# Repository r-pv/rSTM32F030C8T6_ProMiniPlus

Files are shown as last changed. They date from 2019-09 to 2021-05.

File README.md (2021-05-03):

# rSTM32F030C8T6 ProMini+
An ST development board based on the STM32F030C8T6 (Clock: 48MHz, Flash: 64Kb, Ram:8Kb) MCU compatible with STM32Duino (Arduino). 

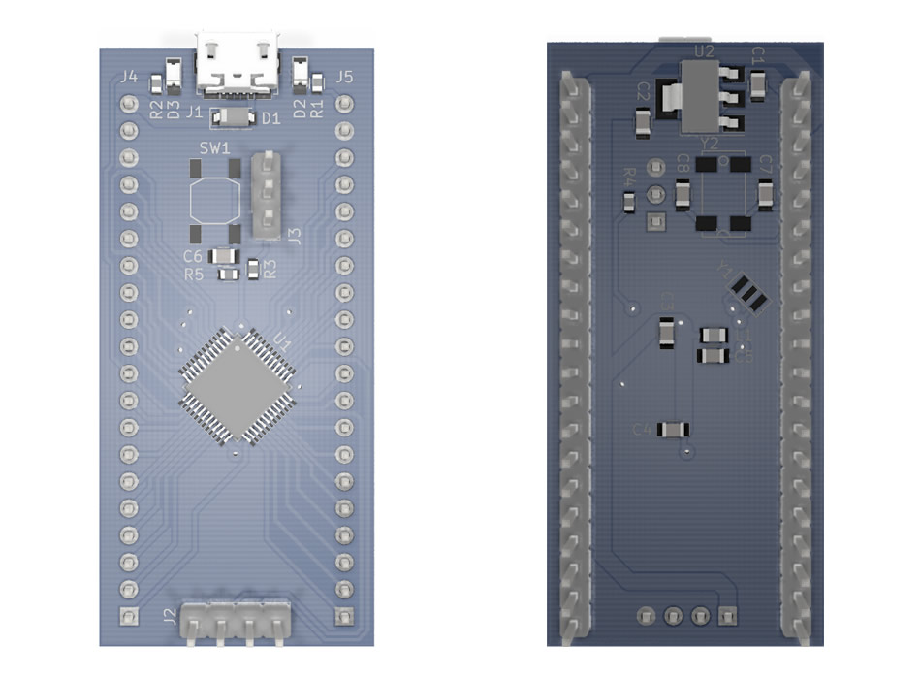
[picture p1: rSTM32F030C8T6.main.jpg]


Pinout:

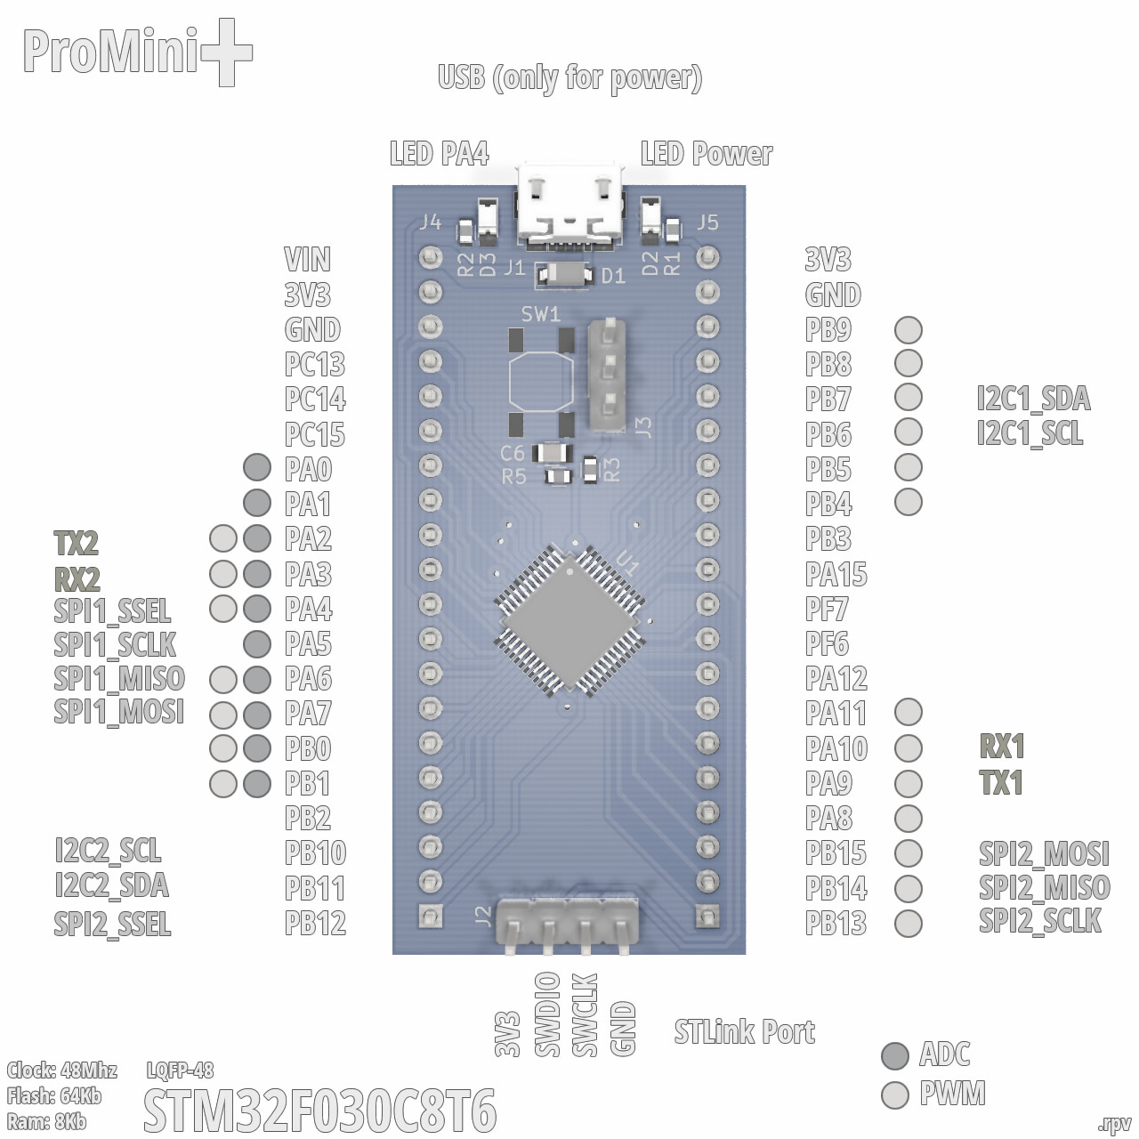
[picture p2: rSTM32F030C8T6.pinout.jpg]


## Files and Folders description

- **RBOARD_F030C8T6** it's the variant board for the STM32 Arduino Core.
- **rSTM32F030C8T6** it's the KiCAD 5.1.2 project.
- **rSTM32F030C8T6.schematic.pdf** the schematic.

## Install

**Update:** STCore v2.0 includes support for this MCU, if you're using STCore v2.0 you don't need to install anything.

- This requires the [STM32 core for arduino](https://github.com/stm32duino/Arduino_Core_STM32/), the ST original.
- I used this [guide to add the board](https://github.com/stm32duino/wiki/wiki/Add-a-new-variant-(board)), you can check it or continue with my suggestions to install the new board.
- Copy the **"RBOARD_F030C8T6"** folder to the Arduino **"variants"** folder, in win7 is located at: **c:\Users\\<USERNAME\>\AppData\Local\Arduino15\packages\STM32\hardware\stm32\1.6.1\variants**
- Edit the **"boards.txt"** file, in win7 is located at a lever up than the "variants" folder, search for the **F030F4** board and add the lines to leave it as I show you next:

```
# DEMO_F030F4 board
# Support: Serial1 (USART1 on PA3, PA2)
GenF0.menu.pnum.DEMO_F030F4=STM32F030F4 Demo board
GenF0.menu.pnum.DEMO_F030F4.upload.maximum_data_size=4096
GenF0.menu.pnum.DEMO_F030F4.upload.maximum_size=16384
GenF0.menu.pnum.DEMO_F030F4.build.mcu=cortex-m0
GenF0.menu.pnum.DEMO_F030F4.build.board=DEMO_F030F4
GenF0.menu.pnum.DEMO_F030F4.build.series=STM32F0xx
GenF0.menu.pnum.DEMO_F030F4.build.product_line=STM32F030x6
GenF0.menu.pnum.DEMO_F030F4.build.variant=DEMO_F030F4
GenF0.menu.pnum.DEMO_F030F4.build.cmsis_lib_gcc=arm_cortexM0l_math

# RBOARD_F030C8T6 board
# Support: Serial1 (USART1 on PA3, PA2)
GenF0.menu.pnum.RBOARD_F030C8T6=STM32F030C8 STProMiniPlus
GenF0.menu.pnum.RBOARD_F030C8T6.upload.maximum_data_size=8192
GenF0.menu.pnum.RBOARD_F030C8T6.upload.maximum_size=65536
GenF0.menu.pnum.RBOARD_F030C8T6.build.mcu=cortex-m0
GenF0.menu.pnum.RBOARD_F030C8T6.build.board=RBOARD_F030C8T6
GenF0.menu.pnum.RBOARD_F030C8T6.build.series=STM32F0xx
GenF0.menu.pnum.RBOARD_F030C8T6.build.product_line=STM32F030x8
GenF0.menu.pnum.RBOARD_F030C8T6.build.variant=RBOARD_F030C8T6
GenF0.menu.pnum.RBOARD_F030C8T6.build.cmsis_lib_gcc=arm_cortexM0l_math
```

## The real board

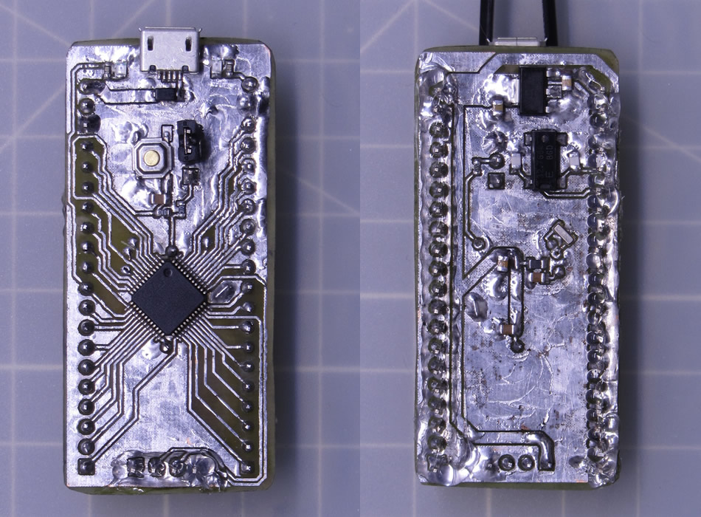
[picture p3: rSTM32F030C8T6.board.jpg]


## Running some tests

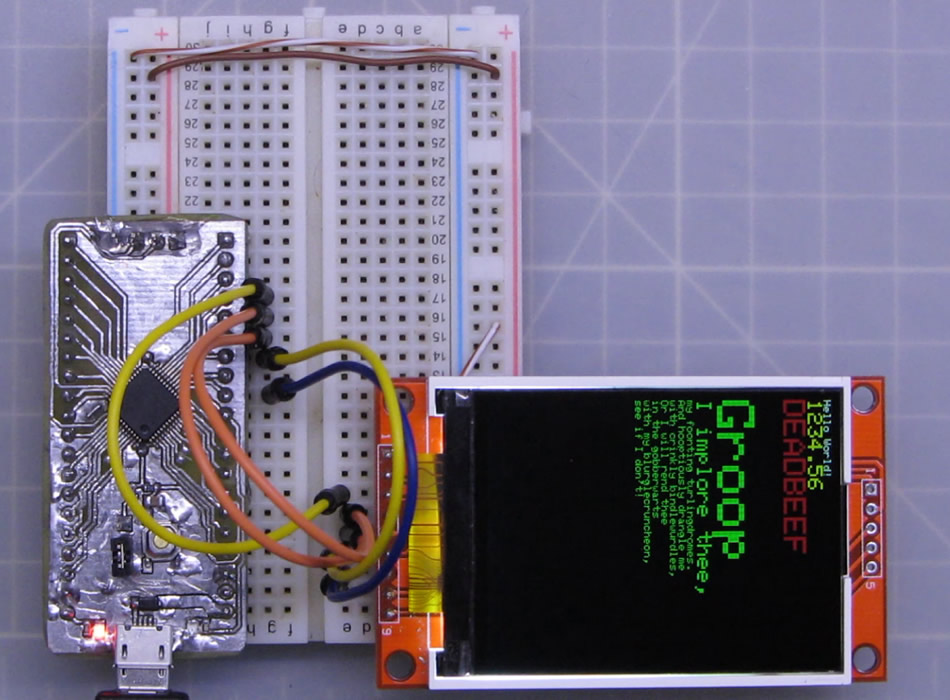
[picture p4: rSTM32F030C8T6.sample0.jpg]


The **ProMini+** running the Adafruit ILI9341 library over hardware SPI.

_Video in progress..._

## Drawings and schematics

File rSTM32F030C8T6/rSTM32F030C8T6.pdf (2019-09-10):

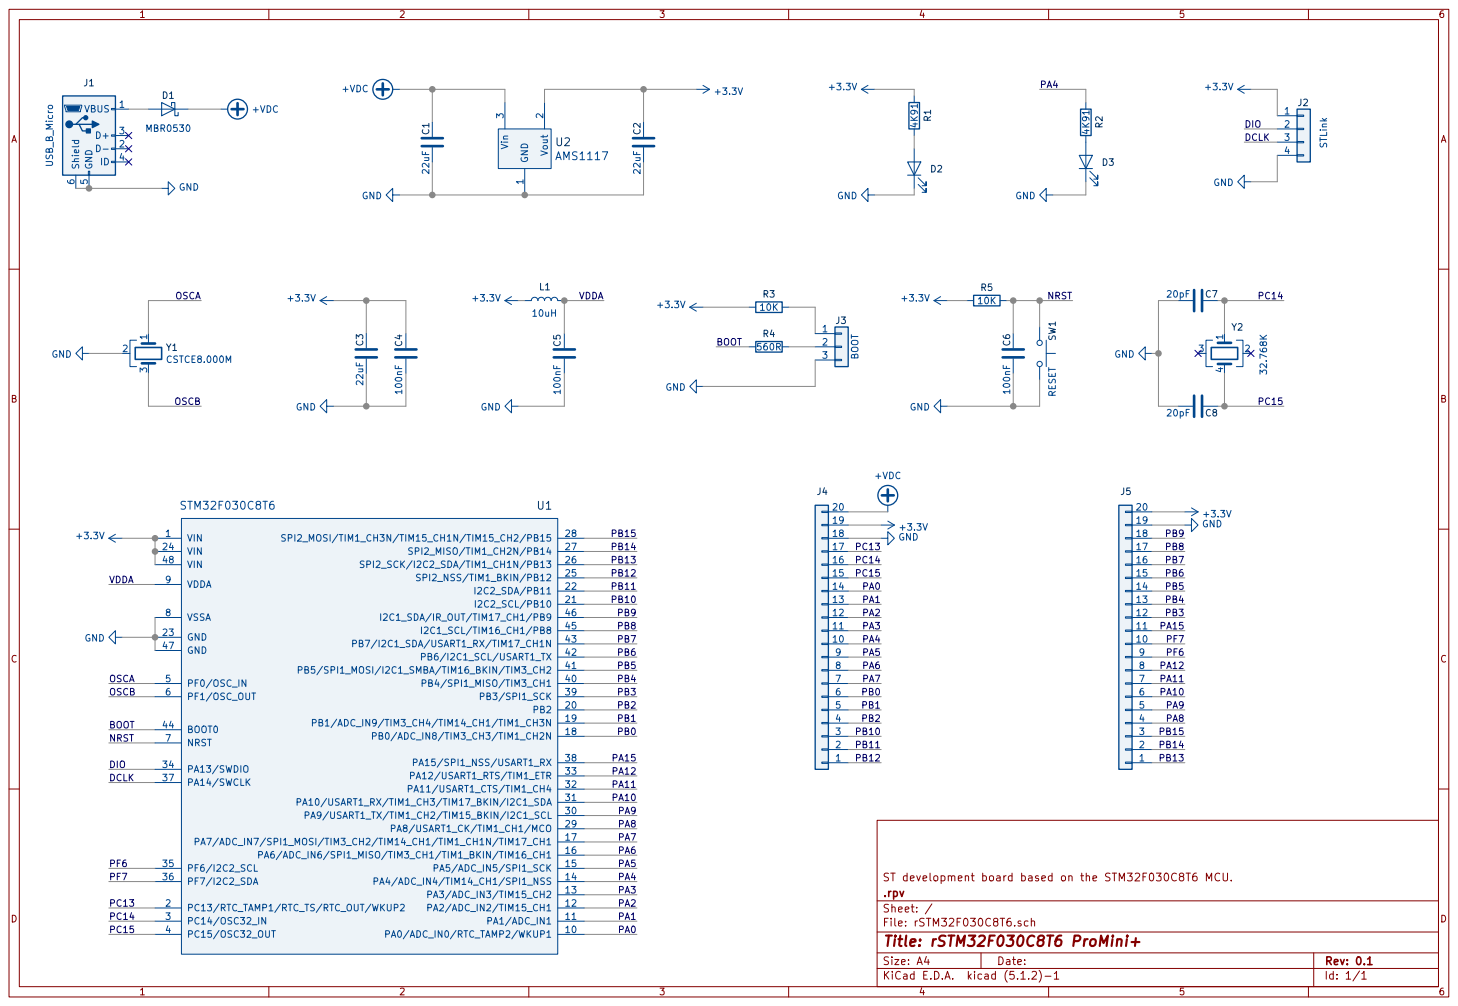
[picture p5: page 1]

.rpv ST development board based on the STM32F030C8T6 MCU. GND

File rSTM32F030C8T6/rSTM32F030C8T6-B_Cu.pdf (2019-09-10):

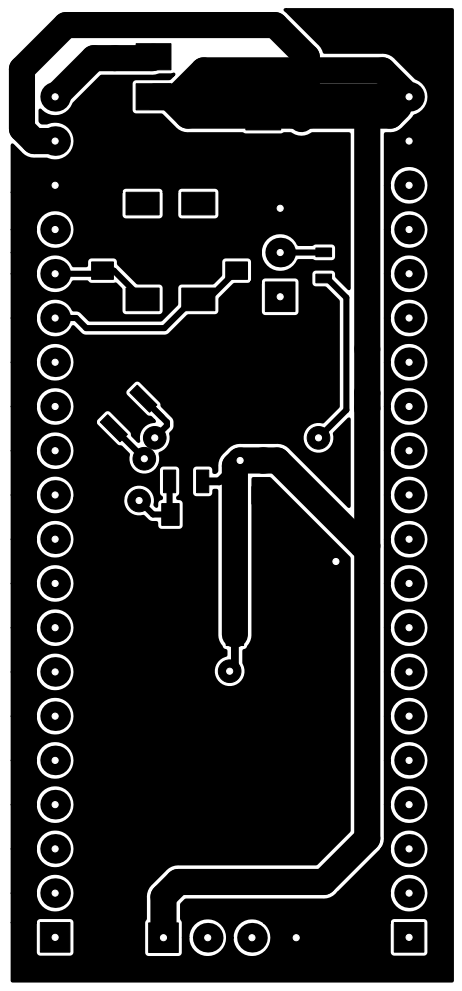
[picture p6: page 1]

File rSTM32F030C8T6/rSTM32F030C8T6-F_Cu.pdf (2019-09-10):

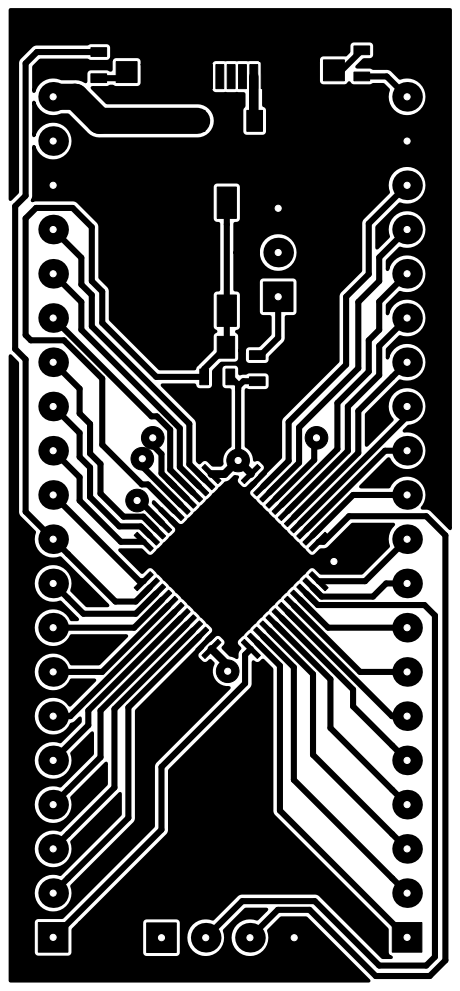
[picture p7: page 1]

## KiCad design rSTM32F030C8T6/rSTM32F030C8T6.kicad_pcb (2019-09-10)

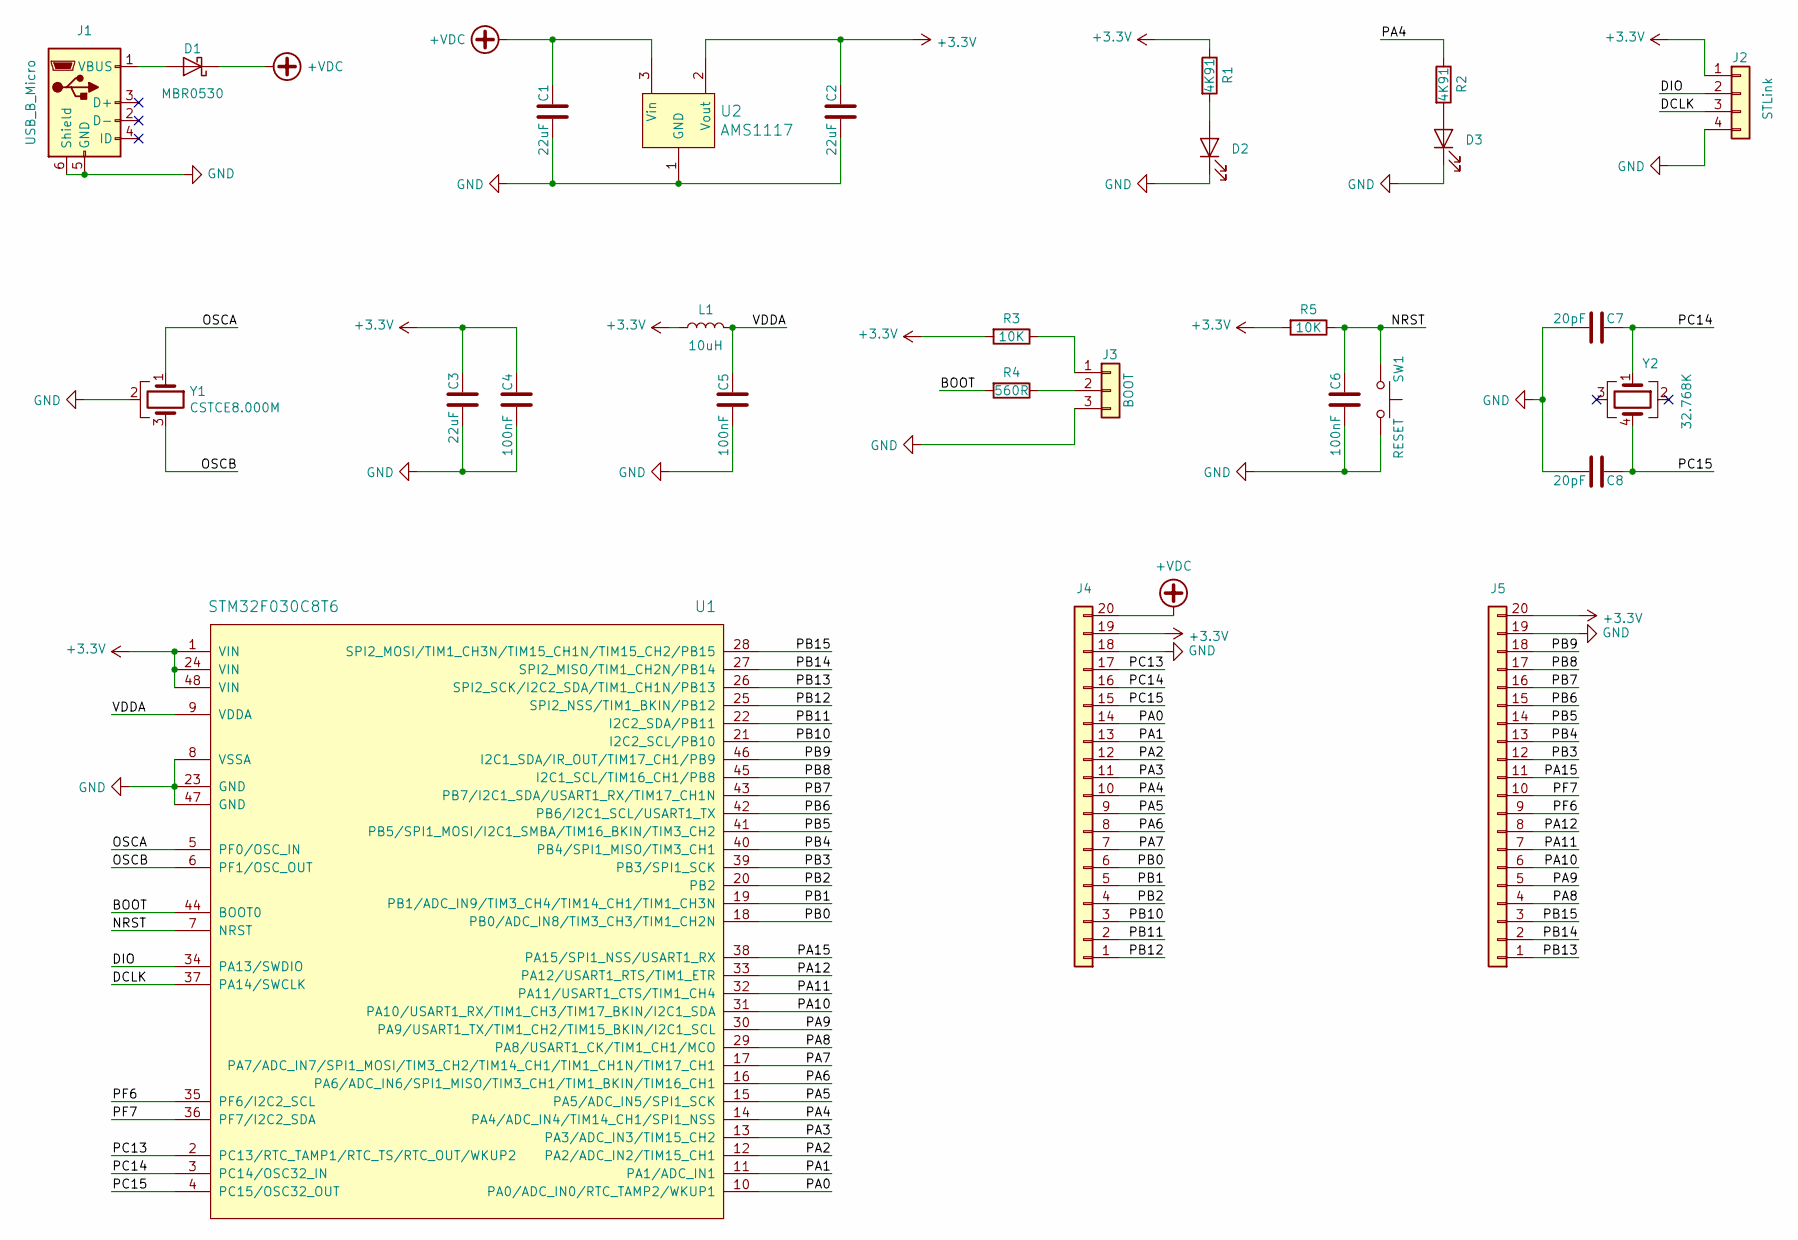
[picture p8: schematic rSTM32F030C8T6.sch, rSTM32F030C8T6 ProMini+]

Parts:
C1, C2, C3: 22uF; C_0805
C4, C5, C6: 100nF; C_0805
C7, C8: 20pF; C_0805
D1: MBR0530; D_SOD-123
D2, D3: LED; LED_0805
J1: USB_B_Micro; USB_Micro-B_Molex_47346-0001
J2: STLink; Pin_Header_Straight_1x04_Pitch2.54mm
J3: BOOT; Pin_Header_Straight_1x03_Pitch2.54mm
J4, J5: Pin_Header_Straight_1x20_Pitch2.54mm
L1: 10uH; L_0805
R1, R2: 4K91; R_0603
R3, R5: 10K; R_0603
R4: 560R; R_0603
SW1: RESET; Switch_SMD_5.2x6.4_reset
U1: STM32F030C8T6; LQFP-48_7x7mm_Pitch0.5mm
U2: AMS1117; SOT-223-3_TabPin2
Y1: CSTCE8.000M; Crystal_CSTCE_3pin_3.2x1.3
Y2: 32.768K; Crystal_4pin_SMD_2.5x4.6

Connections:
+3V3: C2.1, C3.1, C4.2, J2.1, J4.19, J5.20, L1.1, R1.1, R3.2, R5.2, U1.1 (VIN), U1.24 (VIN), U1.48 (VIN), U2.2 (Vout)
+VDC: C1.1, D1.1 (K), J4.20, U2.3 (Vin)
/BOOT: R4.2, U1.44 (BOOT0)
/DCLK: J2.3, U1.37 (PA14/SWCLK)
/DIO: J2.2, U1.34 (PA13/SWDIO)
/NRST: C6.1, R5.1, SW1.1, U1.7 (NRST)
/OSCA: U1.5 (PF0/OSC_IN), Y1.1
/OSCB: U1.6 (PF1/OSC_OUT), Y1.3
/PA0: J4.14, U1.10 (PA0/ADC_IN0/RTC_TAMP2/WKUP1)
/PA1: J4.13, U1.11 (PA1/ADC_IN1)
/PA2: J4.12, U1.12 (PA2/ADC_IN2/TIM15_CH1)
/PA3: J4.11, U1.13 (PA3/ADC_IN3/TIM15_CH2)
/PA4: J4.10, R2.1, U1.14 (PA4/ADC_IN4/TIM14_CH1/SPI1_NSS)
/PA5: J4.9, U1.15 (PA5/ADC_IN5/SPI1_SCK)
/PA6: J4.8, U1.16 (PA6/ADC_IN6/SPI1_MISO/TIM3_CH1/TIM1_BKI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)
/PA7: J4.7, U1.17 (PA7/ADC_IN7/SPI1_MOSI/TIM3_CH2/TIM14_CH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)
/PA8: J5.4, U1.29 (PA8/USART1_CK/TIM1_CH1/MCO)
/PA9: J5.5, U1.30 (PA9/USART1_TX/TIM1_CH2/TIM15_BKIN/I2C1_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)
/PA10: J5.6, U1.31 (PA10/USART1_RX/TIM1_CH3/TIM17_BKIN/I2C1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)
/PA11: J5.7, U1.32 (PA11/USART1_CTS/TIM1_CH4)
/PA12: J5.8, U1.33 (PA12/USART1_RTS/TIM1_ETR)
/PA15: J5.11, U1.38 (PA15/SPI1_NSS/USART1_RX)
/PB0: J4.6, U1.18 (PB0/ADC_IN8/TIM3_CH3/TIM1_CH2N)
/PB1: J4.5, U1.19 (PB1/ADC_IN9/TIM3_CH4/TIM14_CH1/TIM1_CH3N)
/PB2: J4.4, U1.20 (PB2)
/PB3: J5.12, U1.39 (PB3/SPI1_SCK)
/PB4: J5.13, U1.40 (PB4/SPI1_MISO/TIM3_CH1)
/PB5: J5.14, U1.41 (PB5/SPI1_MOSI/I2C1_SMBA/TIM16_BKIN/TIM3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)
/PB6: J5.15, U1.42 (PB6/I2C1_SCL/USART1_TX)
/PB7: J5.16, U1.43 (PB7/I2C1_SDA/USART1_RX/TIM17_CH1N)
/PB8: J5.17, U1.45 (I2C1_SCL/TIM16_CH1/PB8)
/PB9: J5.18, U1.46 (I2C1_SDA/IR_OUT/TIM17_CH1/PB9)
/PB10: J4.3, U1.21 (I2C2_SCL/PB10)
/PB11: J4.2, U1.22 (I2C2_SDA/PB11)
/PB12: J4.1, U1.25 (SPI2_NSS/TIM1_BKIN/PB12)
/PB13: J5.1, U1.26 (SPI2_SCK/I2C2_SDA/TIM1_CH1N/PB13)
/PB14: J5.2, U1.27 (SPI2_MISO/TIM1_CH2N/PB14)
/PB15: J5.3, U1.28 (SPI2_MOSI/TIM1_CH3N/TIM15_CH1N/TIM15_CH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)
/PC13: J4.17, U1.2 (PC13/RTC_TAMP1/RTC_TS/RTC_OUT/WKUP2)
/PC14: C7.1, J4.16, U1.3 (PC14/OSC32_IN), Y2.1
/PC15: C8.1, J4.15, U1.4 (PC15/OSC32_OUT), Y2.4
/PF6: J5.9, U1.35 (PF6/I2C2_SCL)
/PF7: J5.10, U1.36 (PF7/I2C2_SDA)
/VDDA: C5.2, L1.2, U1.9 (VDDA)
GND: C1.2, C2.2, C3.2, C4.1, C5.1, C6.2, C7.2, C8.2, D2.1 (K), D3.1 (K), J1.5 (GND), J1.6 (Shield), J2.4, J3.3, J4.18, J5.19, SW1.2, U1.8 (VSSA), U1.23 (GND), U1.47 (GND), U2.1 (GND), Y1.2
unnamed: D1.2 (A), J1.1 (VBUS)
unnamed: D2.2 (A), R1.2
unnamed: D3.2 (A), R2.2
unnamed: J3.1, R3.1
unnamed: J3.2, R4.1

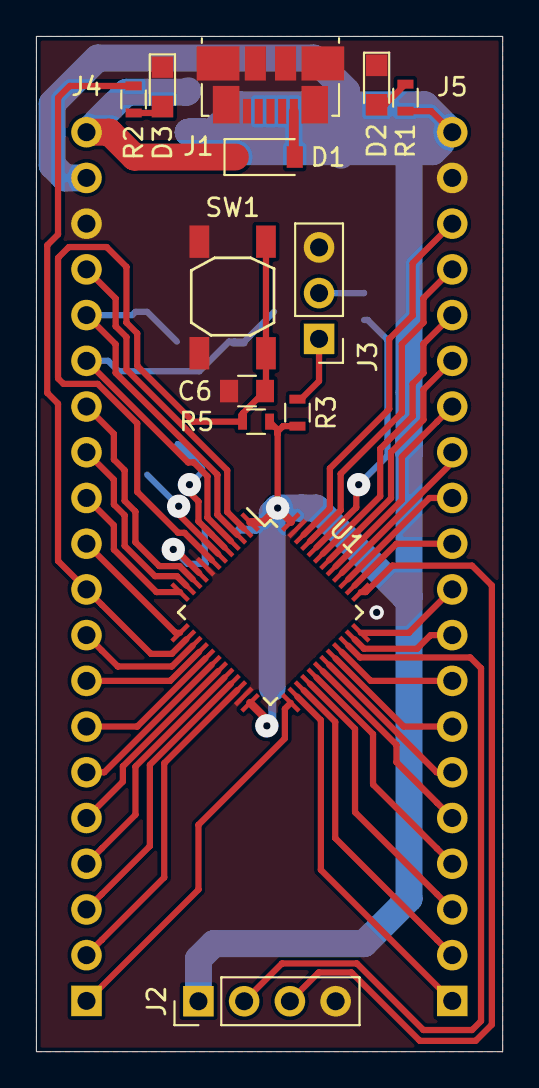
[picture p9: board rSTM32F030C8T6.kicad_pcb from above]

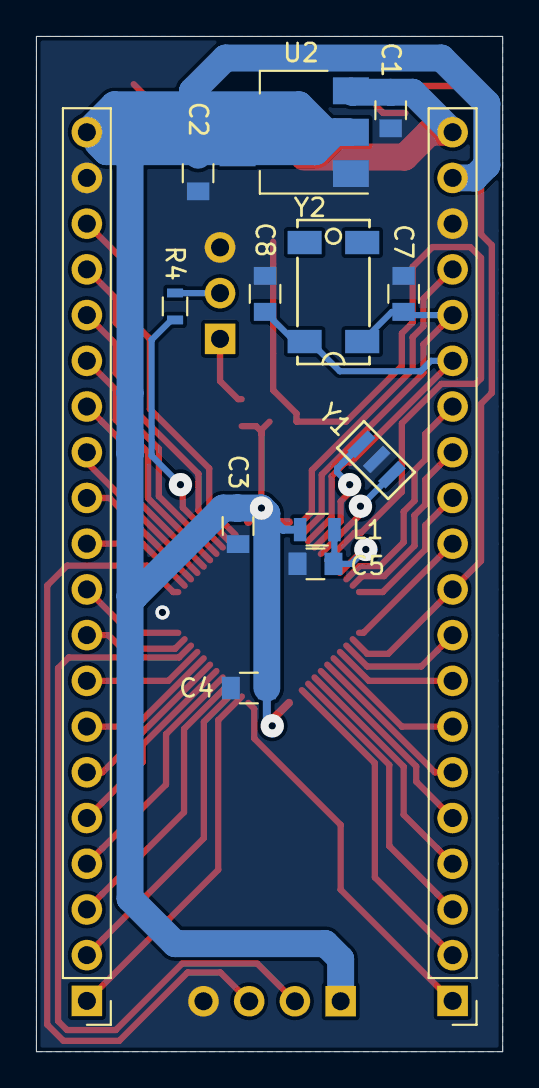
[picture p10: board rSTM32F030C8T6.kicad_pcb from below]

Board: 2 copper layers, 25.9 x 56.4 mm, 27 parts (14 on the bottom side), 50 nets.

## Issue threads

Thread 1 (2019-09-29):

Seems SPI is not working with the latest Arduino_Core_STM32

buptlgq, 2019-09-29:
Try the latest Arduino_Core_STM32 and SPI is not working?
How to use the "stm32f0xx_hal_conf.h" in your respo?

r-pv, 2019-09-29:
Hi, I tested the SPI with a display (ST7735) and a microSD card and all works under the new 1.7 core, I'm using the previous arduino ide, if you're using the latest version may be the problem (I saw a issue on the arduino_core_stm32 github where it says "on hold" for the new IDE).

r-pv, 2019-09-29:
Regarding to the HAL config, I include a HAL with all hardware (I2C, SPI, ADC, etc.) enabled by default, for some reason this file was required for the core were my variants for other boards (f103ve and f405rg) didn't. So, if you're running out of flash and want to disable hardware that you don't  be using just create a file named "hal_conf_extra.h" on your sketch folder and with the lines that you want to disable, example:
```
#define HAL_ADC_MODULE_DISABLED
#define HAL_I2C_MODULE_DISABLED
#define HAL_RTC_MODULE_DISABLED
#define HAL_SPI_MODULE_DISABLED
#define HAL_TIM_MODULE_DISABLED
#define HAL_DAC_MODULE_DISABLED
#define HAL_EXTI_MODULE_DISABLED
#define HAL_ETH_MODULE_DISABLED
#define HAL_SD_MODULE_DISABLED
#define HAL_QSPI_MODULE_DISABLED
```

for other HAL options please check: https://github.com/stm32duino/wiki/wiki/HAL-configuration#core-version--150-1

r-pv, 2019-10-02:
So I got not reply from you, I'll assume that was a "_connection error_" (it happens to me a lot :P ), so I'm closing this issue, but if you still got problems just open a new issue and I'll be back at it. Cheers.

Closed 2019-10-02.

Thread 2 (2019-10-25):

Serial1 not work

leoujz, 2019-10-25:
Serial works, but Serial1 not work on my board, I connect PA2 PA3 as Serial1. I can almost 100% make sure that wiring and board are right. Please take a look at the issue, or give me a hint. Thanks

```
void setup() {

  Serial.begin(9600);

  Serial1.begin(9600);
}

void loop() {
  Serial.println(0);
  Serial1.println(0);
  delay(1000);
}
```

r-pv, 2019-10-25:
Hi, yes, I didn't set serial1, but software serial it's now available on the core 1.7, so you can use any pins you want (just look on the core examples). I was waiting until were possible to set i2c2 and spi2 on the core to set serial1, but you can use right now the software serial, I'll set serial1 ASAP though. Cheers.

r-pv, 2019-10-25:
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

Awesome that you made it work, I didn't know that you can call directly the USART2 definition.
And thanks for the compliment but mostly it's the ST core and the ST guys that made it so easy to add new boards/variants.
Cheers.

Closed 2019-10-26.

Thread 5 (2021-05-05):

flash toolchain

KKuKK, 2021-05-05:
Hi!
Would like to know how you flash these chips, I have a stm32f030c8t6 and try to flash it with
Arduino and Platformio, nothing works. At least not by usb Pin A9,A10. Seems not to be supported.
Would be great to get help, I am just at the end of my ideas, and to my surprise this is the only
webside which is about these chips. All I find is about the stm32f103xxx.
greetings Klaus

r-pv, 2021-05-05:
Hi, I use STLink, since IMO it's the most convenient way to upload sketchs to the STM32/STM8 MCU's, you don't have to mess with boot pins nor bootloaders and you can find clones very cheap on aliexpress/ebay.

If you have an spare bluepill you may want to try to convert it into a [stlink](http://slemi.info/2018/08/14/making-your-own-st-link-v2/)

On the datasheet says this:

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

Pins PA9 and PA10 are the default for the USART so it should work, if not give a try to the PA14 (TX) / PA15 (RX)

KKuKK, 2021-05-06:
Hi
Great to get answer so fast, thanks 😊
I bought a st-link, will take some time to arrive. Is the only way for an stm32f030c8t6
So far I understood.
The funny thing,if I use Arduino ide with stm32f103xx I can flash the blink program
Over pin a9,a10 but it is not running. I guess wrong Variant files, wrong pins, maybe
Wrong starting address.
I tried it with platformio but there is no board for the stm32f030xx
I found a json file for the board folder, but none for the variant folder;
So all messed up, cannot built the hex file.
Right now i am stuck, I bought the smaller stm32 and thought it should be the same
As the bluepill, that was a mistake. I am a beginner with stm, only used atmel
Always bad to start with the most complicated chip 😂😂
Right now I have 3 stm32f030c8t6 and your github link is one of two links Found about
It.
So, how do you integrate these chip in platformio? Even if i get the st-link I cannot
Flash the chip, because it is not offered as a board. Only hundred versions of
Stm32f103.
Thanks for your answer
Greetings klaus
Von meinem iPhone gesendet

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

r-pv, 2021-05-06:
I have used platformio IDE a few times, but I haven't idea how to create variants for this IDE, the variant on this repo it's for arduino IDE but the new version of this core (ST Core v2.0, that was released a few days) already has support for most of the F030XX series, so if you're using  using arduino ID upgrade the core to the newer 2.0 version or you'll have to install this variant manually (instructions are on the readme/main of this repo). Maybe that's why you can't program correctly the MCU, the USART interface it's the same as the bluepill (F103), the F030C just has one boot pin).

KKuKK, 2021-05-07:
Great you answer so fast, thanks a lot!
I already installed the boards in the arduino
Ide. I found two json links, stm32duino....and dan.drown.org....One link is all about stm32f103xxxx
The other mostly stm32f030xxxx.
In the dan.org is my chip included, but no option for
Uploading with Pin a9,a10. There is only an option for stm32cubeprogrammer, which i don’t have. It is for the pins clk,dio on the top back of the chip i assume.

I am looking for the json link st core, maybe I have the wrong board packages.
No, cannot find other json links, cannot find st core as a board.
Do you have a different json link?
Thanks for help
Greetings klaus

Von meinem iPhone gesendet

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

KKuKK, 2021-05-07:
Hi again
Here is what i have installed in the arduino ide under boards

Stm32fxx/gd32f1xx boards by stm32duino version 2021.3.18

And

Stm32 mcu based boards by stmicroelectronics version 2.0.0

In the second is my board with the only upload option as i mentioned above which don’t work for me with an usb2ttl chip.
May be there are more boards to install
Greetings klaus

Von meinem iPhone gesendet

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
>>> Am 07.05.2021 um 01:39 schrieb .rpv ***@***.***>:
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

KKuKK, 2021-05-09:
Hi 🙋
No problem 😉 , don’t expect answers at all.
It’s a kindness of you.
That’s what I tried several times.
Upload method stm32cubeprogrammer->serial
But I get the message „“programmer not found“
That’s why I thought I need these programmer and it will not work with a simple
Usb2ttl converter.
Which software  of your st-link do I need?
The funny thing is, if I select the wrong chip,
The bluepill, which have the uploadoption
Serial, than it is flashing. So it was quite clear
That it must work in principal.
Thanks a lot for you help. Always sad to buy new stuff and getting nothing to run.
So I assume I only need these software for the cubprogrammer even when I use the usb2ttl converter.
Greetings klaus

Von meinem iPhone gesendet

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

r-pv, 2021-05-09:
The STM32CubeProgrammer, the stlink requires this software in order to be able of make uploads, but I'm not sure if it's required for ttl uploads, the error message makes me think that probably be the case but it's weird that you can do uploads on the blue pill and not on this board.

KKuKK, 2021-05-09:
Hi thanks for the answer
Exactly that makes me wonder. Wouldn’t matter if it will run with bluepill settings, but
It isn’t.
The difference is, there ist a plain serial option for bluepill, unfortunately not for the
Stm32f030xx. My guess is with the cubeprogrammer upload is a special instruction set necessary. But really don’t know.
But just to be sure you have installed software for the st-link?
If you can upload code to the stm32f030 with an usb2ttl it should also work for me.
Have to find out where the difference is
Between your settings an my one.😎
My best guess ist, that the serial option for the cubeprogrammer uses a customized instruction set for the upload, no matter if you use an usb2ttl or an St-link. The software will adjust the sequences for the chip.
Would mean i probably need the real st-link hardware to install the software.
Will give it a try.
Greetings klaus

Von meinem iPhone gesendet

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

r-pv, 2021-05-09:
``But just to be sure you have installed software for the st-link?``
Yes, for stlink uploads the STM32CubeProgrammer is mandatory, that's why I wasn't sure if this will be available on your menus.

But still, using stlink you just connect it, hit the compile/upload button and that's it, not messing with boot pins, bootloaders, no matter what stm32 flavor nor sequences.

There are some bootloaders that you can load into the bluepill (F3XXXX series, F4XXXX series, MCUs with considerable flash and USB capabilities) that allow you to do uploads through the USB port,  that can be really convenient too.

KKuKK, 2021-05-10:
Hi
It works!! Thanks a lot for our help. I installed the STM32cubeprogrammer and after
restart of the Arduino IDE I was able to flash the chip with a blink test.
There seems to be a different Pin declaration, because just a number 13
don’t work. Has to call the Pin PC13.
The other setback is, the usb is not working with Serial.begin();
But this is onl a matter of reading, the most important thing is
to get a programm to the chip
greetings Klaus

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

KKuKK, 2021-05-13:
Hi again!
I made the changes in the board.txt file and add the variant folder as described and wanted to
test your code with the tft in the picture. I can only find the folder
rSTM32F030C8T6 in which, to be honest, I can see no code for arduino.
It looks like assambler, its like chinese to me
How can I flash the chip with your demo code with the ST7735 TFT with the Arduino IDE?
I searched for a library for this chip and the ST7735 but was not able to compile it.
Either not enough flash space, which is weird, because it works for the halve sized
atmega328, or it just don’t compile with errors.

I tried the library TFT_eSPI from Bodmer and Arduino_fast_stm from cbm80amiga.
TFT_eSPI from Bodmer is to large, even for the simplest program, the ohter has lot
of errors.

Thanks for help.

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

r-pv, 2021-05-13:
Hi, sorry for the late reply.

This boards have 2 usart and the stcore has the software serial library, all works, I can't remember if I've tested the usart 2, but it should work. And I always use the PXX pin nomenclature (PA0, PB1, ..., ), but yes, there is a bit of mess regarding to the pin naming, I think that is inherited from the arduino API.
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
KKuKK, 2021-05-19:
Hi
Great answer and a lot stuff to read, lot of new links. This will take long time to check them all.yesterday I got the st-link, very fast
Delivery, so in theory nothing should prevent me from programming 🤣

At least I was not completely wrong.
The code is indeed very large, even with a small program.

On an attiny you can have code of 2kb running.

I could compile a test code  for the tft st7735
With the adafruit_st7735 lib

Now i got a tft screen so i can test  it.
I did not have to make any changes, so I doubt this will really run.

The reason for me to try the stm chip was the larger flash and sram, not the Speed.
I built a cycling computer with gps and eeprom data logging on an atmega32 with
8mhz and it works, but now I am nearly
At the finishline regarding flash.

Now I have some doubt whether I can port this code from atmega to stm. There is also a
Bmp180 chip for height and temperature built in.

If every lib like the tft libs are so conflicted with the stm it will be a hard ride 😳
Greetings klaus

Von meinem iPhone gesendet

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

r-pv, 2021-05-20:
I use the F030F4 as the stm32 attiny, it's a tssop20 package with 16kb of flash, but depending on what peripherals you use it feels like an atmega328p of 512b-1kb flash, sadly ST didn't have any mcu of a sot-23 o similar size package.

To me the sale point of the stm32 it's that you have like a hundred mcu's to choose with all the combinations possibles: low power/consumption, dacs, adc 16bits, crypto, dfu, giant flash sizes (up to 1mb), fast clocks (at least 480mhz), etc.

The stcore compatibility with the arduino api it's really great overall, you don't find a lot of problems with libraries, there is this particularly case with the tft library because it has to send a lot of data as fast as possible and due to the same compatibility most of the speeds are set by default at the avr-atmel values, the adc y pwm channels also are set by default at 10bit and 8bit respectively when this are at least 12bit and 16bit on all stm32 series (on the api documentation says how to change it).

But libraries, like the u8g2 runs fast and perfectly on the f030 and all the stm32 mcu's that I have tested on both hardware i2c and spi, I just don't have tested the software i2c but probably it's a nono anyways.

There's other library that gave me a lot of problems and I didn't make it work on the f030's, was the IR remote library, so timer-related libraries may also be an issue, I haven't tried again though.

KKuKK, 2021-05-20:
Thanks for your very helpful answers

There is obviously no really one perfect chip. It took quite some time
To make stuff with the atmel chips and I still more or less are a dependend arduino
Ide or platformio ide user. With the new stm chip I realized how much work really has to
Be done to program such chips. All the basic configuration are already done I asume
In the core files.

Good to know that the adc is 10 bit configured, not 12!
Good to know that most libs are working for stm!

You mentioned the different core for cmb80amiga libs. Is there an easy way to integrate this core in arduino, too? If these basics are not set up properly, I don't think I would have any success.

It took me a long time to get a simple rf 433mhz chip with all different atmel
Chips to communicate. Even for atmel chips the timing is only to be done, if you look into
The data sheet of ever single chip.

Don't think I can make it again with stm🤓
I will take it slowly, no need to hurry. But now I bought the stm, so I have to look
how to make something out of it.

It took me a lot of research to make it with the eps8266 chips, too. Its a really
Challenging stuff. But here you have the additional problem of ever changing
Internet standards and ever changing cores. It's like alice in wonderland,
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

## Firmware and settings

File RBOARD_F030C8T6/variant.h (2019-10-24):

/*
 *******************************************************************************
 * Copyright (c) 2017, STMicroelectronics
 * All rights reserved.
 *
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
 * THIS SOFTWARE IS PROVIDED BY THE COPYRIGHT HOLDERS AND CONTRIBUTORS "AS IS"
 * AND ANY EXPRESS OR IMPLIED WARRANTIES, INCLUDING, BUT NOT LIMITED TO, THE
 * IMPLIED WARRANTIES OF MERCHANTABILITY AND FITNESS FOR A PARTICULAR PURPOSE ARE
 * DISCLAIMED. IN NO EVENT SHALL THE COPYRIGHT HOLDER OR CONTRIBUTORS BE LIABLE
 * FOR ANY DIRECT, INDIRECT, INCIDENTAL, SPECIAL, EXEMPLARY, OR CONSEQUENTIAL
 * DAMAGES (INCLUDING, BUT NOT LIMITED TO, PROCUREMENT OF SUBSTITUTE GOODS OR
 * SERVICES; LOSS OF USE, DATA, OR PROFITS; OR BUSINESS INTERRUPTION) HOWEVER
 * CAUSED AND ON ANY THEORY OF LIABILITY, WHETHER IN CONTRACT, STRICT LIABILITY,
 * OR TORT (INCLUDING NEGLIGENCE OR OTHERWISE) ARISING IN ANY WAY OUT OF THE USE
 * OF THIS SOFTWARE, EVEN IF ADVISED OF THE POSSIBILITY OF SUCH DAMAGE.
 *******************************************************************************
 */
#ifndef _VARIANT_ARDUINO_STM32_
#define _VARIANT_ARDUINO_STM32_

/*----------------------------------------------------------------------------
 *        Headers
 *----------------------------------------------------------------------------*/
#ifdef __cplusplus
extern "C"{
#endif // __cplusplus

/*----------------------------------------------------------------------------
 *        Pins
 *----------------------------------------------------------------------------*/
//.with.the.USB.on.the.bottom.and.left-to-right-to-top.naming;
// Left.Side
#define PB13   0
#define PB14   1
#define PB15   2
#define PA8    3
#define PA9    4
#define PA10   5
#define PA11   6
#define PA12   7
#define PF6    8
#define PF7    9
#define PA15   10
#define PB3    11
#define PB4    12
#define PB5    13
#define PB6    14
#define PB7    15
#define PB8    16
#define PB9    17
// Bottom.side
//USB
// Right.side
#define PC13   18
#define PC14   19
#define PC15   20
#define PA0    21
#define PA1    22
#define PA2    23
#define PA3    24
#define PA4    25
#define PA5    26
#define PA6    27
#define PA7    28
#define PB0    29
#define PB1    30
#define PB2    31
#define PB10   32
#define PB11   33
#define PB12   34
// top.side.stlink
#define PA13   35
#define PA14   36

// Define pin names to match digital pin number --> Dx
// It could be used with preprocessor tests (e.g. #if PXn == 3)
// so an enum will not work.
// !!!
// !!! Copy the digitalPin[] array from the variant.cpp
// !!! and remove all '_': PX_n --> PXn
// !!! For NC, comment the line to warn x pin number is NC
// !!! // x is NC
// !!! For duplicated pin name, comment the line to warn x pin number
// !!! is PXn which is already defined with y pin number
// !!! // x is PXn (y)
// !!! Ex:
// !!! ...
// !!! #define PA4  20 // A14
// !!! #define PB4  21
// !!! #define PB5  22
// !!! #define PB3  23
// !!! // 24 is PA4 (20)
// !!! // 25 is PB4 (21)
// !!! #define PA2  26 // A15
// !!! ...
//#define PXn x

// This must be a literal
// It is used with preprocessor tests (e.g. #if NUM_DIGITAL_PINS > 3)
// so an enum will not work.
#define NUM_DIGITAL_PINS        47

// Allow to define Arduino style alias for analog input pin number --> Ax
// All pins are digital, analog inputs are a subset of digital pins
// and must be contiguous to be able to loop on each value
// This must be a literal with a value less than or equal to MAX_ANALOG_INPUTS
// defined in pin_arduino.h
// It is used with preprocessor tests (e.g. #if NUM_ANALOG_INPUTS > 3)
// so an enum will not work.
// !!!
// !!! It must be aligned with the number of analog PinName
// !!! defined in digitalPin[] array in variant.cpp
// !!!
#define NUM_ANALOG_INPUTS       10
// Define digital pin number of the first analog input  (i.e. which digital pin is A0)
// First analog pin value (A0) must be greater than or equal to NUM_ANALOG_INPUTS
#define NUM_ANALOG_FIRST        21

// Below ADC, DAC and PWM definitions already done in the core
// Could be redefined here if needed
// ADC resolution is 12bits
//#define ADC_RESOLUTION          12
//#define DACC_RESOLUTION         12

// PWM resolution
//#define PWM_RESOLUTION          8
//#define PWM_FREQUENCY           1000
//#define PWM_MAX_DUTY_CYCLE      255

// On-board LED pin number
#define LED_BUILTIN             PA4
#define LED_GREEN               LED_BUILTIN

// On-board user button
#define USER_BTN                x

// Below SPI and I2C definitions already done in the core
// Could be redefined here if differs from the default one
// SPI Definitions
// SPI Definitions
#define PIN_SPI_SS              PA4
#define PIN_SPI_MOSI            PA7
#define PIN_SPI_MISO            PA6
#define PIN_SPI_SCK             PA5

// I2C Definitions
#define PIN_WIRE_SDA            PB7 // Default for Arduino connector compatibility
#define PIN_WIRE_SCL            PB6  // Default for Arduino connector compatibility

// Timer Definitions
// Do not use timer used by PWM pins when possible. See PinMap_PWM.
#define TIMER_TONE              TIM17

// Do not use basic timer: OC is required
#define TIMER_SERVO             TIM16  //TODO: advanced-control timers don't work

// UART Definitions
#define SERIAL_UART_INSTANCE    1
// Default pin used for 'Serial' instance
// Mandatory for Firmata
#define PIN_SERIAL_RX           PA10
#define PIN_SERIAL_TX           PA9

// UART Definitions
// Define here Serial instance number to map on Serial generic name
//#define SERIAL_UART_INSTANCE    x //ex: 2 for Serial2 (USART2)
// DEBUG_UART could be redefined to print on another instance than 'Serial'
//#define DEBUG_UART              ((USART_TypeDef *) U(S)ARTX) // ex: USART3
// DEBUG_UART baudrate, default: 9600 if not defined
//#define DEBUG_UART_BAUDRATE     x
// DEBUG_UART Tx pin name, default: the first one found in PinMap_UART_TX for DEBUG_UART
//#define DEBUG_PINNAME_TX        PX_n // PinName used for TX


// Optional PIN_SERIALn_RX and PIN_SERIALn_TX where 'n' is the U(S)ART number
// Used when user instanciate a hardware Serial using its peripheral name.
// Example: HardwareSerial mySerial(USART3);
// will use PIN_SERIAL3_RX and PIN_SERIAL3_TX if defined.
//#define PIN_SERIALn_RX          x // For U(S)ARTn RX
//#define PIN_SERIALn_TX          x // For U(S)ARTn TX
//#define PIN_SERIALLP1_RX        x // For LPUART1 RX
//#define PIN_SERIALLP1_TX        x // For LPUART1 TX

// SD card slot Definitions
// SD detect signal can be defined if required
//#define SD_DETECT_PIN           x
// SD Read/Write timeout, default value defined in STM32SD library
//#define SD_DATATIMEOUT          x

#ifdef __cplusplus
} // extern "C"
#endif
/*----------------------------------------------------------------------------
 *        Arduino objects - C++ only
 *----------------------------------------------------------------------------*/
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

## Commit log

2019-09-10 stm32duino variant.
2019-09-11 HAL_conf it's do required by the arduino ide.
2019-09-23 Pinout update, added ADC and PWM pins.
2019-10-24 Fixed a bug with the analogs.
    Fixed a mistake I made.
    [variant.cpp, variant.h]
2020-05-17 PinOut updated, added: SPI2, UART2 and I2C2
